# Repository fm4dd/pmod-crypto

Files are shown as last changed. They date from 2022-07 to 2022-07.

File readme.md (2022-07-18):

## CRYPTO PMOD

### Description

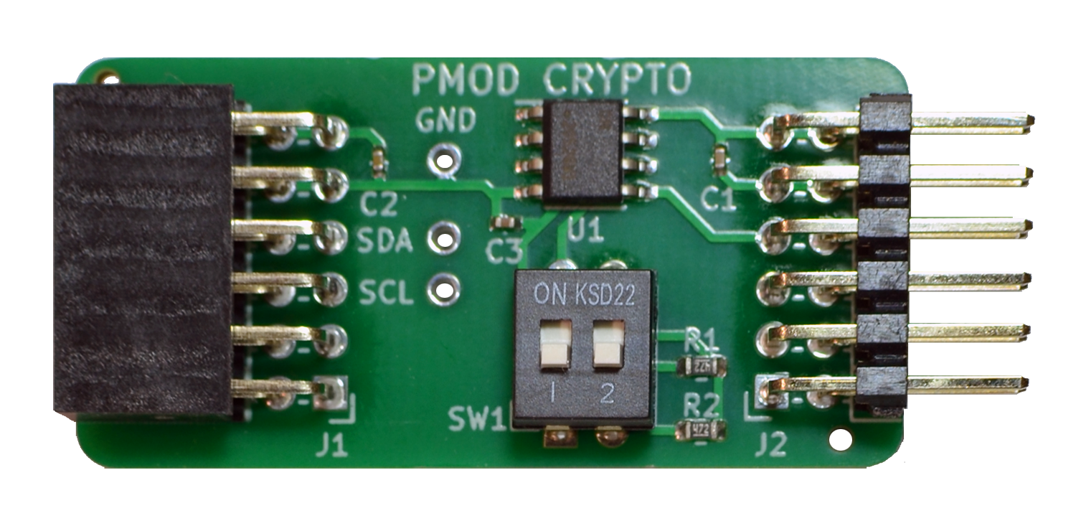
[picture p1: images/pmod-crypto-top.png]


This PMOD connects the Microchip ATECC508A  crypto authentication device over I2C, 
using Digilent's PMOD interface type 6A per PMOD specification v1.3.1. 
The PMOD module can be chained to add additional I2C devices to the bus. 
The onboard I2C bus pull-up resistors can be enabled/disabled, using the DIP switch.

http://fpga.fm4dd.com/

This design is registered under the OSHWA Open Source Hardware Self-Certification:



### Schematic
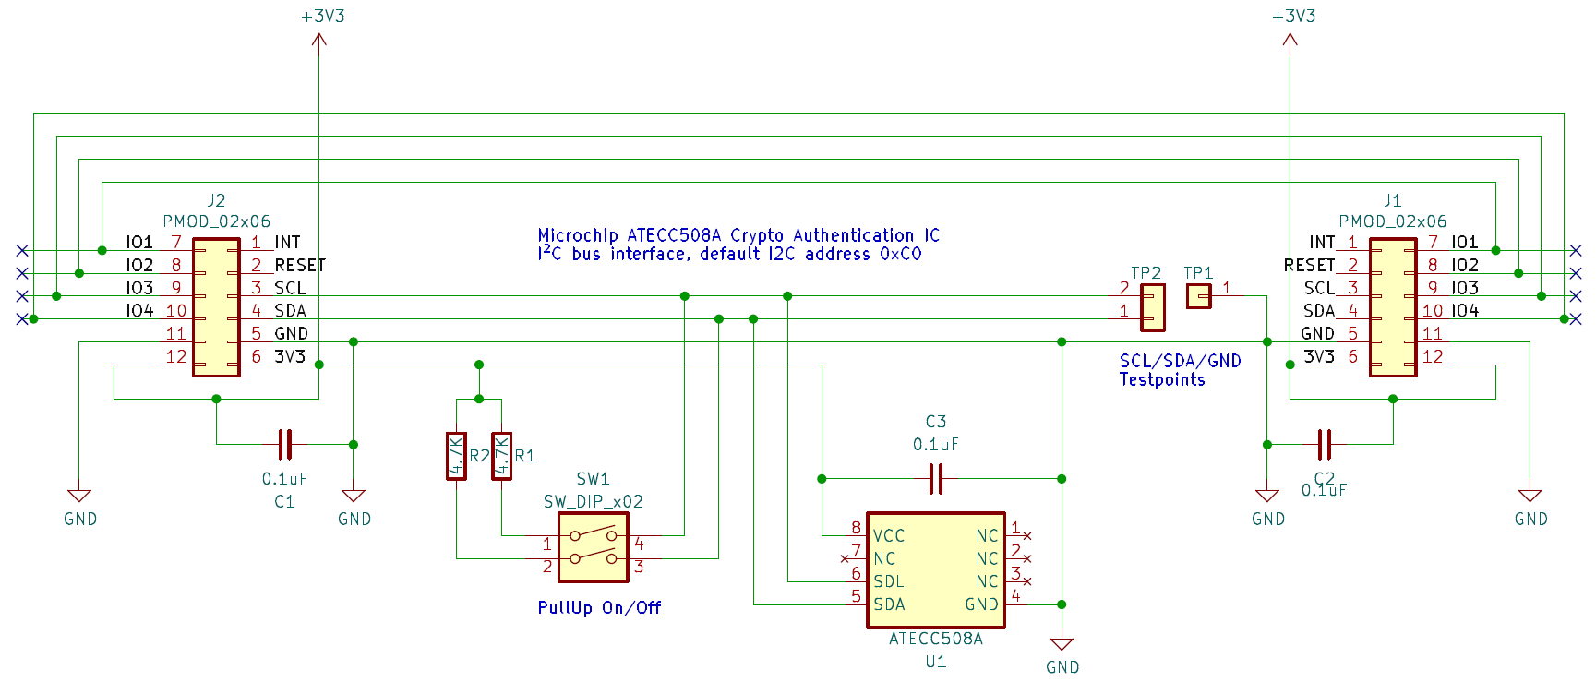
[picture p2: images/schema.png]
CRYPTO PMOD Schematics


### PCB Gerber
[CRYPTO PMOD Gerber V1.0](20220624-crypto-gerber-v10.zip)

### PMOD Interface Pin Assignments

Pin  |	Label |	Description   | Pin  |	Label |	Description
-----|--------|---------------|------|--------|---------------
1    |	-     |	Not connected |7     | -      | Not connected
2    |	-     |	Not connected |8     | -      | Not connected
3    |	SCL   |	I2C clock     |9     | -      | Not connected
4    |  SDA   | I2C data      |10    | -      | Not connected
5    |  GND   | ground        |11    | GND    | ground
6    |  3V3   | 3.3V          |12    | 3V3    | 3.3V

All pins are passed through from connector J1 to J2, allowing to chain multiple type 6/6A PMODs.

### Example Operation

#### Linux / Raspberry Pi

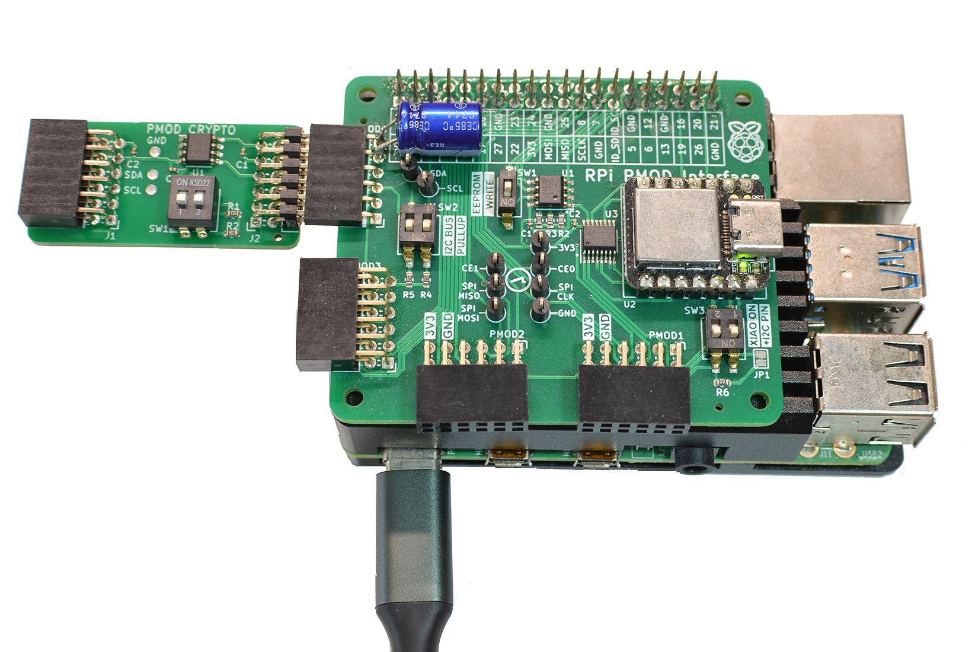
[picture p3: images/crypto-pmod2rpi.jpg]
CRYPTO PMOD on PMOD2RPI


Above shows the CRYPTO PMOD, connected to a [PMOD2RPI](https://github.com/fm4dd/pmod2rpi) interface board. When connected through the PMOD4 connector, the module can be controlled from the Raspberry Pi under Linux. Using i2cdetect, the ATECC508A IC responds under I2C bus address 0x60 (default).

```
pi@pi-ms05:~ $ i2cdetect 1
WARNING! This program can confuse your I2C bus, cause data loss and worse!
I will probe file /dev/i2c-1.
I will probe address range 0x08-0x77.
Continue? [Y/n]
     0  1  2  3  4  5  6  7  8  9  a  b  c  d  e  f
00:                         -- -- -- -- -- -- -- --
10: -- -- -- -- -- -- -- -- -- -- -- -- -- -- -- --
20: -- -- -- -- -- -- -- -- -- -- -- -- -- -- -- --
30: -- -- -- -- -- -- -- -- -- -- -- -- -- -- -- --
40: -- -- -- -- -- -- -- -- -- -- -- -- -- -- -- --
50: -- -- -- -- -- -- -- -- -- -- -- -- -- -- -- --
60: 60 -- -- -- -- -- -- -- -- -- -- -- -- -- -- --
70: -- -- -- -- -- -- -- --
```

To interact with the crypto IC under Linux, I am using "atecc-util", located at https://github.com/wirenboard/atecc-util.  This program is a frontend to the official Microchip library cryptoauthlib at https://github.com/MicrochipTech/cryptoauthlib.

Getting the client program:

```
pi@pi-ms05:~/atecc508a $ git clone https://github.com/wirenboard/atecc-util
Cloning into 'atecc-util'...
...
Receiving objects: 100% (351/351), 83.59 KiB | 2.88 MiB/s, done.
Resolving deltas: 100% (200/200), done.
```

Configure the I2C bus ID as 1, to match the RPI PMOD connection:

```
pi@pi-ms05:~/atecc508a/atecc-util $ vi config.h
#pragma once

#define DEFAULT_I2C_BUS 1
#define DEFAULT_I2C_SLAVE 0xC0

#define MAX_CMDS 32
```

Building the client program:

```
pi@pi-ms05:~/atecc508a $ cd atecc-util/
pi@pi-ms05:~/atecc508a/atecc-util $ git submodule init
pi@pi-ms05:~/atecc508a/atecc-util $ git submodule update
remote: Enumerating objects: 47, done.
remote: Counting objects: 100% (37/37), done.
remote: Total 47 (delta 36), reused 36 (delta 36), pack-reused 10
Unpacking objects: 100% (47/47), 12.65 KiB | 172.00 KiB/s, done.
From https://github.com/MicrochipTech/cryptoauthlib
 * branch              b976f640e4643a18876e0e5e600c8106f1bbe078 -> FETCH_HEAD
Submodule path 'cryptoauthlib': checked out 'b976f640e4643a18876e0e5e600c8106f1bbe078'
pi@pi-ms05:~/atecc508a/atecc-util $ make
...
```

Build result:

```
pi@pi-ms05:~/atecc508a/atecc-util $ ls -l ./atecc
-rwxr-xr-x 1 pi pi 439020 Jul  9 10:55 ./atecc
pi@pi-ms05:~/atecc508a/atecc-util $ ./atecc -h
atecc-util 0.4.7 (v0.4.7-dirty), build Jul  9 2022 10:54:59
Usage: ./atecc [-bshv] -c "cmd1 cmd1_args" [-c "cmd2 cmd2_args"]

        -b <i2c bus ID>
                I2C bus ID ATECC is connected to. Default is 9
        -s <i2c slave ID>
                I2C slave ID of ATECC. Default is 0xc0
        -c "cmd [arg1 [arg2 ...]]"
                Command and its arguments.
        -h[cmd_name]
                Print this help message or help message of specific command.
        -r <num_retries>
                Max number of retries for some commands. Default is 10
        -v      Print version and exit
```

Reading data from the crypto IC (factory-fresh  state):

```
pi@pi-ms05:~/atecc508a/atecc-util $ ./atecc -c 'info'
Found ATECC508A
pi@pi-ms05:~/atecc508a/atecc-util $ ./atecc -c 'serial'
0123**************
```

Below example dumps all configuration data (factory-fresh  state):

```
pi@pi-ms05:~/atecc508a/atecc-util $ ./atecc -c 'dump-config -'
============= Config zone dump: =============

000: 01         001: 23         002: 98         003: 3A
004: 00         005: 00         006: 50         007: 00
...
064: 00         065: 00         066: 00         067: 00
068: FF         069: FF         070: FF         071: FF
072: FF         073: FF         074: FF         075: FF
076: FF         077: FF         078: FF         079: FF
080: FF         081: FF         082: FF         083: FF
084: 00         085: 00         086: 55         087: 55
088: FF         089: FF         090: 00         091: 00
092: 00         093: 00         094: 00         095: 00
096: 33         097: 00         098: 33         099: 00
100: 33         101: 00         102: 1C         103: 00
104: 1C         105: 00         106: 1C         107: 00
108: 1C         109: 00         110: 1C         111: 00
112: 3C         113: 00         114: 3C         115: 00
116: 3C         117: 00         118: 3C         119: 00
120: 3C         121: 00         122: 3C         123: 00
124: 3C         125: 00         126: 1C         127: 00
===== Individual locks configuration ==
 Slot 00: unlocked
...
 Slot 15: unlocked

===== Slot configurations============
=========================  Slot: 0   ==================
Decoding SlotConfig value = 0x2083
Read key (except ECC private keys): 3
 If slot contains ECC private keys:
  External signatures of arbitrary messages are enabled: 1
  Internal signatures are enabled: 1
  ECDH operation is permitted for this key: 0
   ECDH master secret output mode: 0
NoMac bit: 0
LimitedUse bit: 0
EncryptRead bit: 0
IsSecret bit: 1
Write key: 0
Write config: 0x2 (hex) = 0010 (bin)
  Write cmd: Never
  DeriveKey cmd: Roll without MAC
  GenKey cmd: may be used
  PrivWrite cmd: Forbidden
-------------
Decoding KeyConfig value = 0x0033
Private bit: 1
PubInfo bit: 1
KeyType: 4 [P256]
Lockable bit: 1
ReqRandom bit: 0
ReqAuth bit: 0
AuthKey: 0
IntrusionDisable bit: 0
X509id: 0
...
=========================  Slot: 15   ==================
Decoding SlotConfig value = 0x8FAF
Read key (except ECC private keys): 15
 If slot contains ECC private keys:
  External signatures of arbitrary messages are enabled: 1
  Internal signatures are enabled: 1
  ECDH operation is permitted for this key: 1
   ECDH master secret output mode: 1
NoMac bit: 0
LimitedUse bit: 1
EncryptRead bit: 0
IsSecret bit: 1
Write key: 15
Write config: 0x8 (hex) = 1000 (bin)
  Write cmd: Never
  DeriveKey cmd: Can't be used
  GenKey cmd: may NOT be used
  PrivWrite cmd: Forbidden
-------------
Decoding KeyConfig value = 0x001C
Private bit: 0
PubInfo bit: 0
KeyType: 7 [SHA or other]
Lockable bit: 0
ReqRandom bit: 0
ReqAuth bit: 0
AuthKey: 0
IntrusionDisable bit: 0
X509id: 0
```

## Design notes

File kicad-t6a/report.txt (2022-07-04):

Info: Processing symbol 'C1:Capacitor_SMD:C_0402_1005Metric'.
Info: Processing symbol 'J1:FM4DD:PMODPinSocket_2x06_P2.54mm_Horizontal'.
Info: Processing symbol 'C2:Capacitor_SMD:C_0402_1005Metric'.
Info: Processing symbol 'U1:Package_SO:SOIC-8_5.23x5.23mm_P1.27mm'.
Info: Processing symbol 'C3:Capacitor_SMD:C_0402_1005Metric'.
Info: Processing symbol 'J2:FM4DD:PMODHeader_2x06_P2.54mm_Horizontal'.
Info: Processing symbol 'H1:FM4DD:SMD_TOOLING_HOLE_1.152mm'.
Info: Processing symbol 'SW1:Button_Switch_THT:SW_DIP_SPSTx02_Slide_6.7x6.64mm_W7.62mm_P2.54mm_LowProfile'.
Info: Processing symbol 'L1:FM4DD:KiCad-Logo2_5mm_SilkScreen'.
Info: Processing symbol 'H2:FM4DD:SMD_TOOLING_HOLE_1.152mm'.
Info: Processing symbol 'TP1:FM4DD:Testpoint_PinHeader_1x02_P2.54mm_Vertical'.
Info: Processing symbol 'R2:Resistor_SMD:R_0603_1608Metric'.
Info: Processing symbol 'H3:FM4DD:SMD_TOOLING_HOLE_1.152mm'.
Info: Processing symbol 'TP2:FM4DD:TestPoint_PinHeader_1x01_P2.54mm_Vertical'.
Info: Processing symbol 'R3:Resistor_SMD:R_0603_1608Metric'.
Updated C1 properties.
Updated C2 properties.
Updated C3 properties.
Updated H1 properties.
Add net unconnected-(U1-Pad7).
Updated H2 properties.
Connected U1 pin 7 to unconnected-(U1-Pad7).
Updated H3 properties.
Connected U1 pin 8 to +3V3.
Updated J1 properties.
Updated J2 properties.
Updated L1 properties.
Updated R2 properties.
Updated R3 properties.
Updated SW1 properties.
Updated TP2 properties.
Updated TP1 properties.
Added U1 (footprint 'Package_SO:SOIC-8_5.23x5.23mm_P1.27mm').
Changed REF** reference designator to U1.
Changed U1 value from SOIC-8_5.23x5.23mm_P1.27mm to ATECC508A.
Updated U1 symbol association from  to /f2eb82bf-7622-435a-8d7b-bf1dafc22cf6.
Updated U1 properties.
Add net unconnected-(U1-Pad1).
Connected U1 pin 1 to unconnected-(U1-Pad1).
Add net unconnected-(U1-Pad2).
Connected U1 pin 2 to unconnected-(U1-Pad2).
Add net unconnected-(U1-Pad3).
Connected U1 pin 3 to unconnected-(U1-Pad3).
Connected U1 pin 4 to GND.
Connected U1 pin 5 to /SDA.
Connected U1 pin 6 to /SCL.
Warning: No net found for symbol H1 pin 1.
Warning: No net found for symbol H2 pin 1.
Warning: No net found for symbol H3 pin 1.
Warning: Copper zone on layer B.Cu at (197.6649 mm, 65.1836 mm) has no pads connected.

Info: Total warnings: 1, errors: 0.

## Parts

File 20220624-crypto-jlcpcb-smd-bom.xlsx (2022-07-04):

Comment | Designator | Footprint | LCSC Part #（optional）
100nF | C1 | C_0402
100nF | C2 | C_0402
100nF | C3 | C_0402
4.7K | R1, R2 | R_0603
ATECC508A | U1 | SOIC-8

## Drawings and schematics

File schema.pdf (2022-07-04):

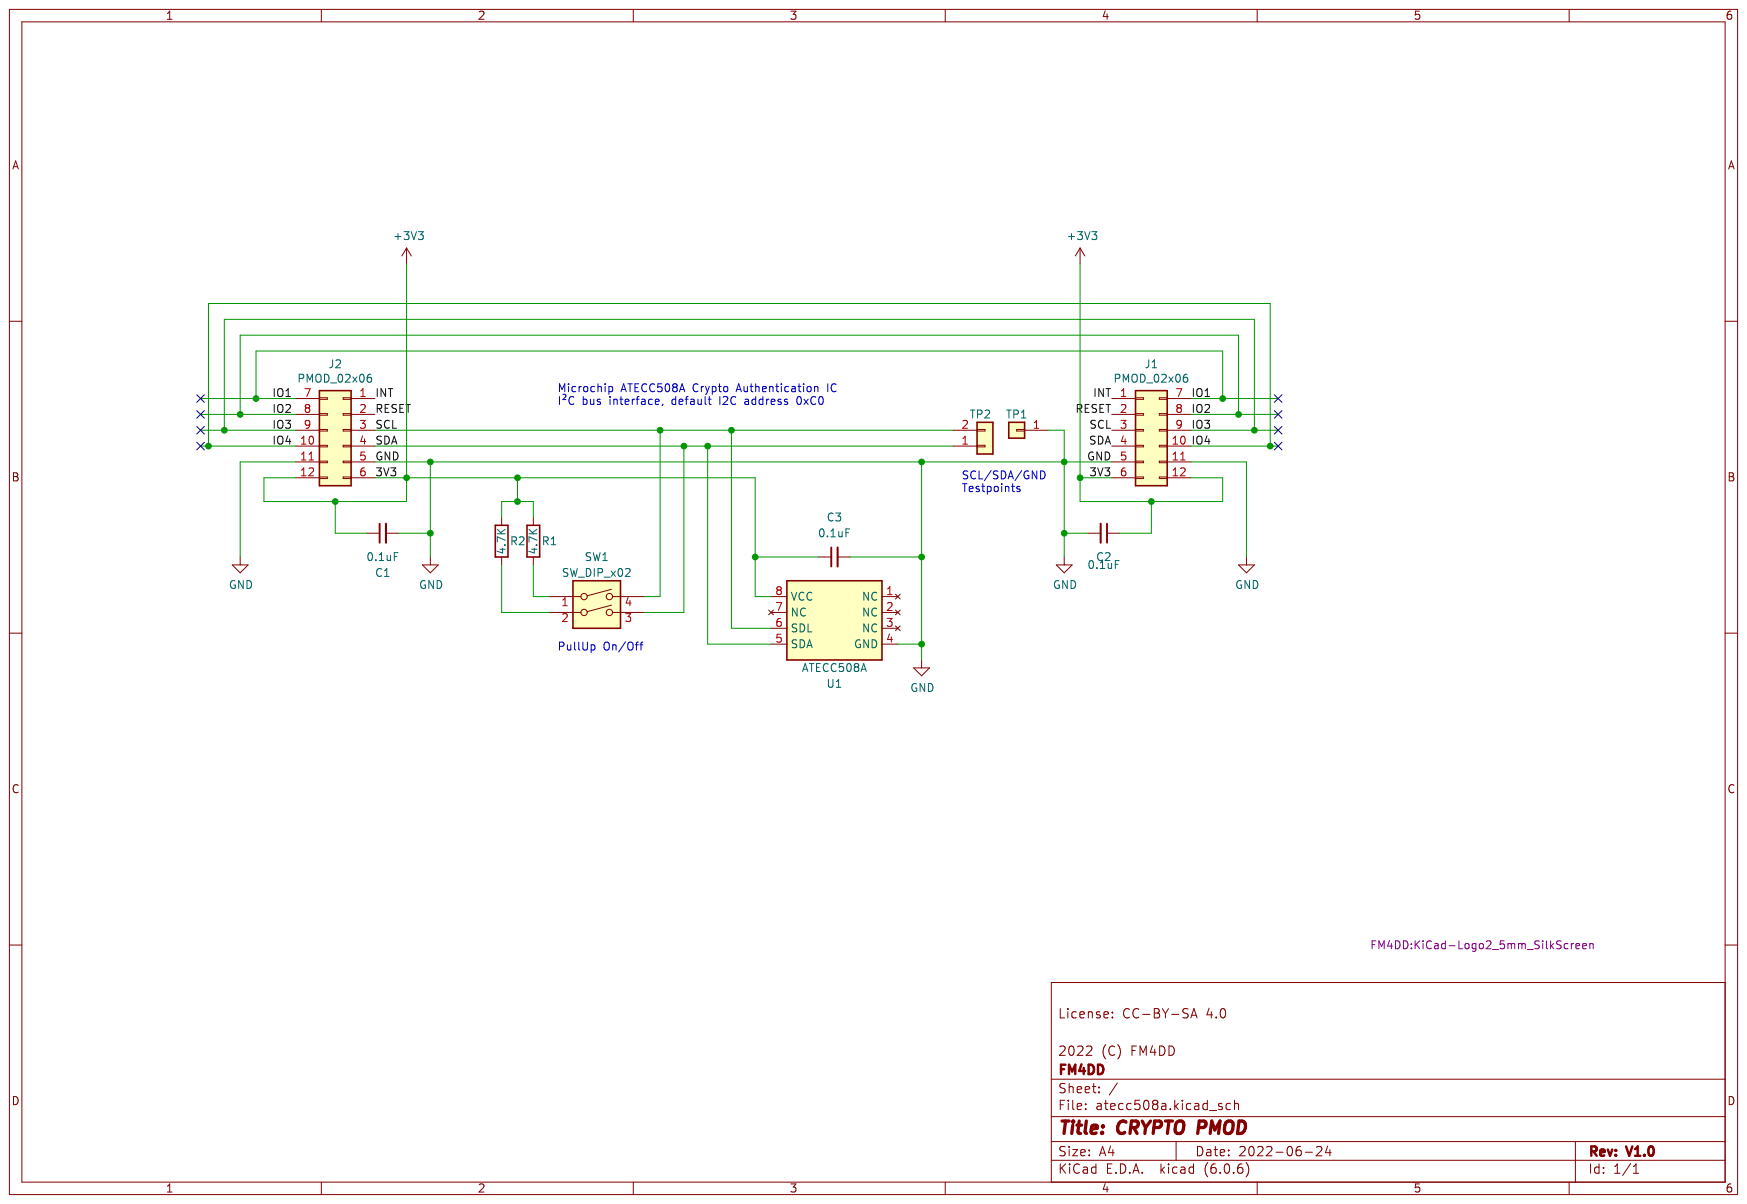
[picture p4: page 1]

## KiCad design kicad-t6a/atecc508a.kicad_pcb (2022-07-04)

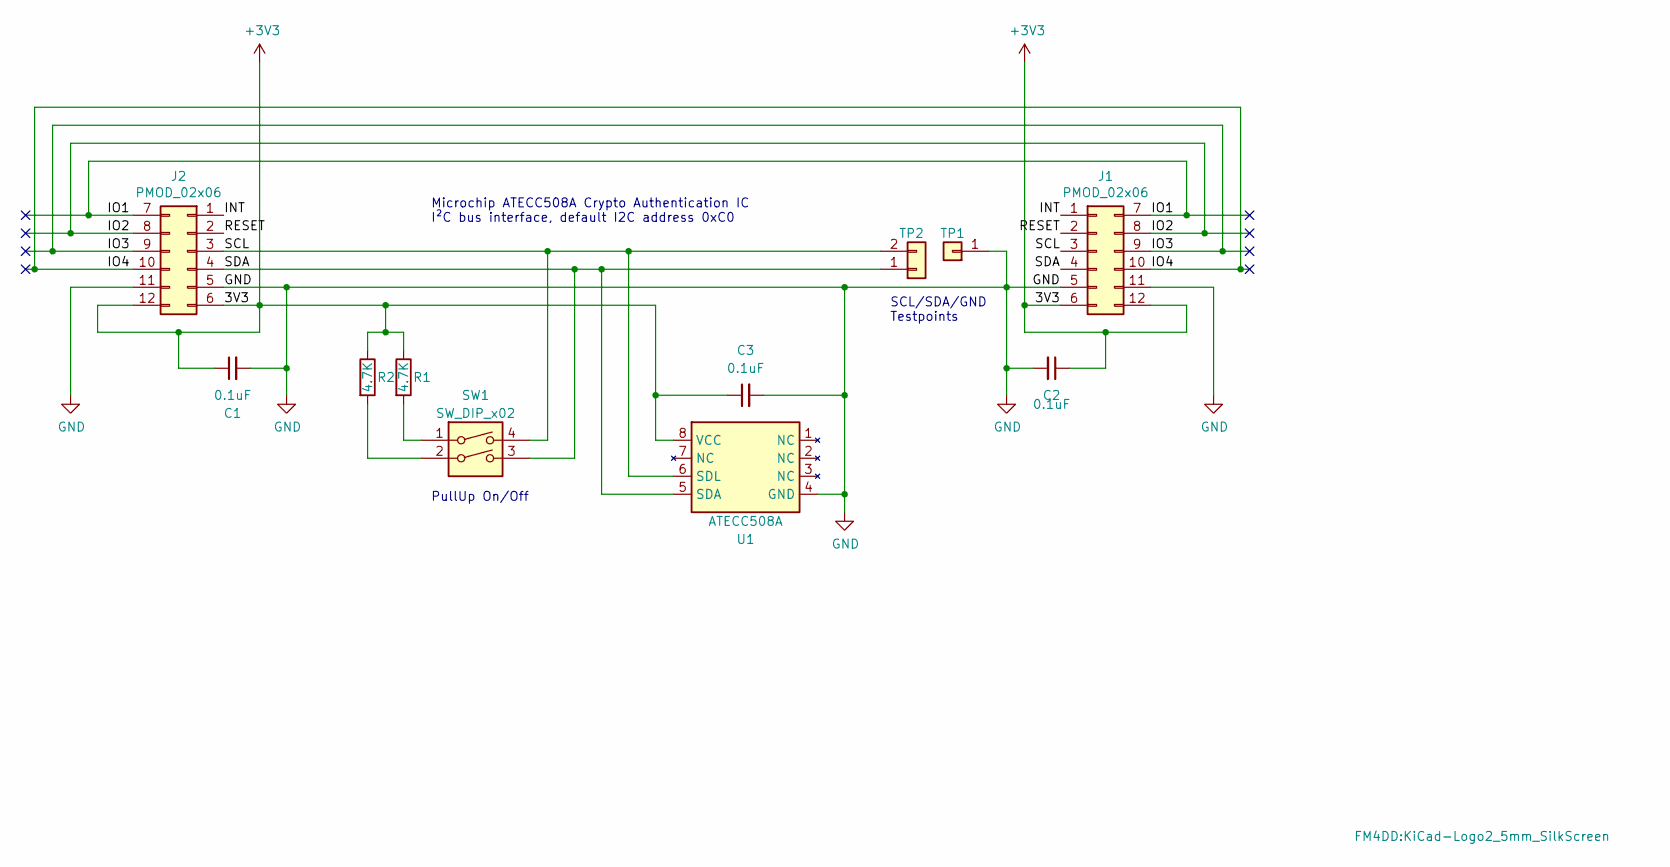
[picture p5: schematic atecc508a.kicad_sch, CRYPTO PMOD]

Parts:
C1, C2, C3: 0.1uF; C_0402_1005Metric
J1: PMOD_02x06; PMODPinSocket_2x06_P2.54mm_Horizontal
J2: PMOD_02x06; PMODHeader_2x06_P2.54mm_Horizontal
L1: Logo_KiCad_5mm; KiCad-Logo2_5mm_SilkScreen
R1, R2: 4.7K; R_0603_1608Metric
SW1: SW_DIP_x02; SW_DIP_SPSTx02_Slide_6.7x6.64mm_W7.62mm_P2.54mm_LowProfile
TP1: TestPoint_Conn_01x01; TestPoint_PinHeader_1x01_P2.54mm_Vertical
TP2: Conn_01x02; Testpoint_PinHeader_1x02_P2.54mm_Vertical
U1: ATECC508A; SOIC-8_3.9x4.9mm_P1.27mm

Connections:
+3V3: C1.1, C2.1, C3.1, J1.6, J1.12, J2.6, J2.12, R1.1, R2.1, U1.8 (VCC)
/INT: J1.1, J2.1
/IO1: J1.7, J2.7
/IO2: J1.8, J2.8
/IO3: J1.9, J2.9
/IO4: J1.10, J2.10
/RESET: J1.2, J2.2
/SCL: J1.3, J2.3, SW1.4, TP2.2, U1.6 (SDL)
/SDA: J1.4, J2.4, SW1.3, TP2.1, U1.5 (SDA)
GND: C1.2, C2.2, C3.2, J1.5, J1.11, J2.5, J2.11, TP1.1, U1.4 (GND)
unnamed: R1.2, SW1.1
unnamed: R2.2, SW1.2

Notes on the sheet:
SCL/SDA/GND Testpoints
PullUp On/Off
Microchip ATECC508A Crypto Authentication IC I²C bus interface, default I2C address 0xC0

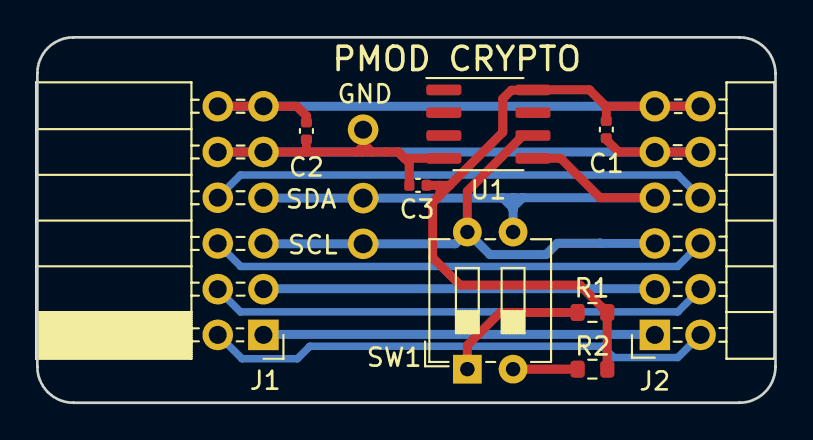
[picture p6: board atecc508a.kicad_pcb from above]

Board: 2 copper layers, 41.0 x 20.3 mm, 13 parts (1 on the bottom side), 12 nets.

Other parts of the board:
Ref**: JLCPCB_Order_Number_Placeholder

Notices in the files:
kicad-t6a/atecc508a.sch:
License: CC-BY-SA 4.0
